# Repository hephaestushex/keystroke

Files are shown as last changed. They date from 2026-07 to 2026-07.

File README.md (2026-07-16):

Keystroke Picture








# Keystroke

_A mini piano-based arcade game, based off the arcade game Grand Piano Keys_

by [@crkalapat](https://github.com/crkalapat), [@hephaestushex](https://github.com/hephaestushex) and [@ceansounet](https://github.com/ceansounet)

_Demo placeholder here_

## How to Play

On bootup, Keystroke will show the title screen, and the current high score. Hit any one of
the four piano keys at the bottom, and gameplay will start immediately along with a 30 second timer.

On screen, there will be colored rectangles that correspond to a key that you must physically
press on the arcade cabinet. Hitting the correct key will cause the next key to fall down for you to
hit. Hitting the wrong key will cause a brief waiting penalty, indicating by the flashing wrong key,
but you can continue playing (if there's time left) after the penalty.

Once 30 seconds ends (as indicated by the 4 digit 7 segment display), the game will be over. You can
view your score, and you will also be notified if you beat the high score, which is stored in flash
memory.

## Features

- 4 Cherry MX Compatible Key Switches
- 2.8" TFT LCD Display (ST7789)
- 30 mm Speaker with PAM8403 amp
- 4 Digit 7 Segment Display (TM1637)
- Orpheus Pico v2 MCU

## Firmware

Keystroke uses PlatformIO, with earlephilhower's build.

## Schematic

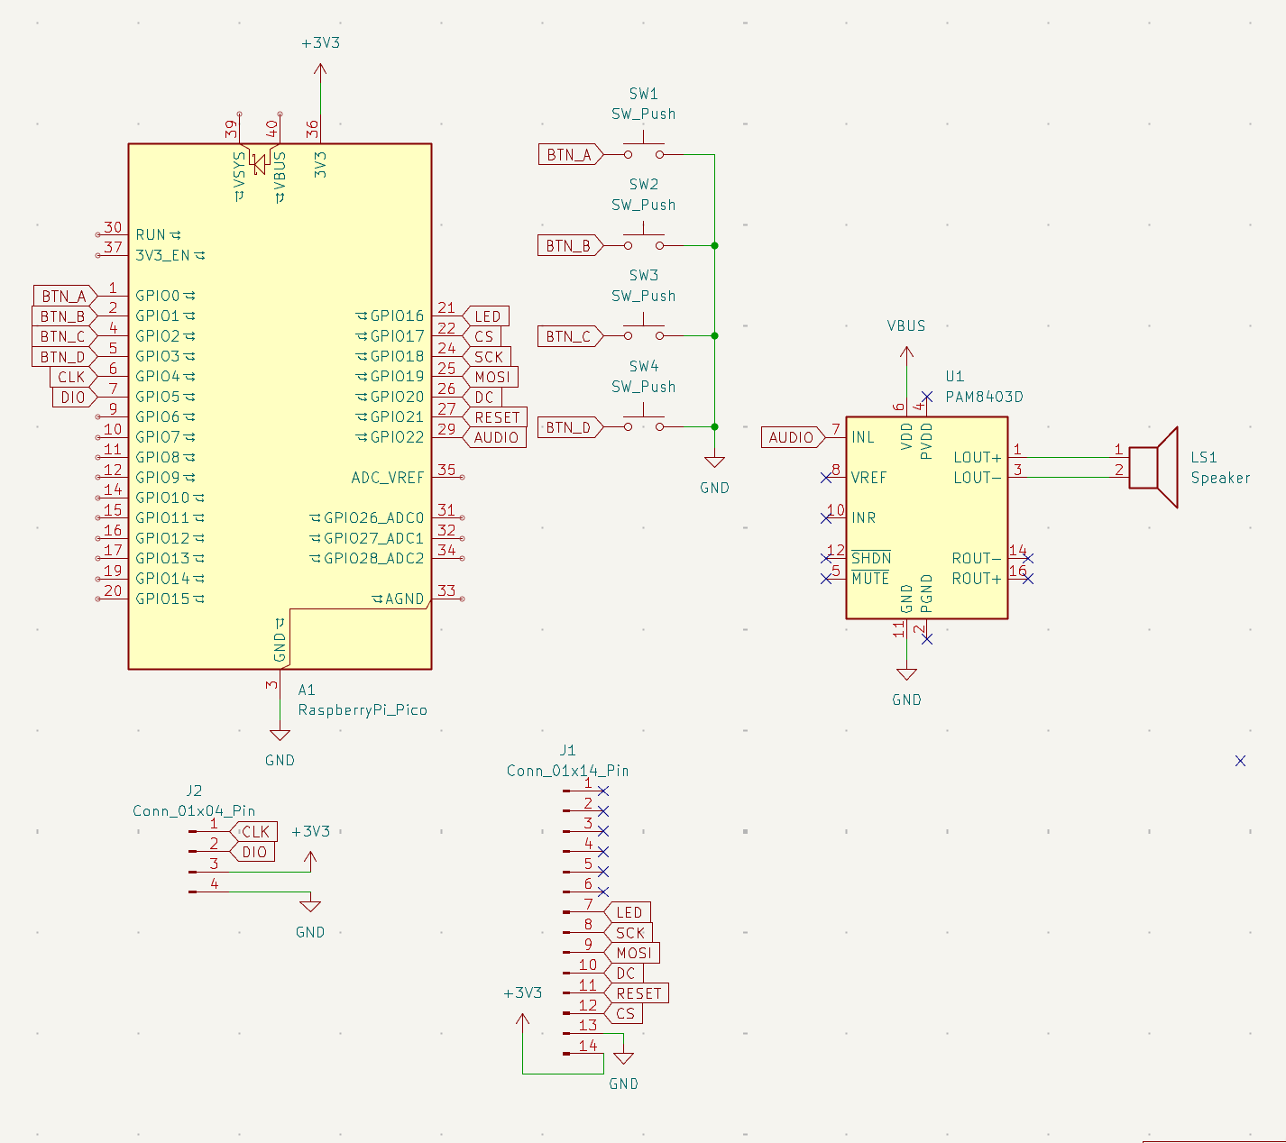
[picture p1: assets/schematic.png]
Schematic Picture


## CAD

You can view the full assembled cabinet as a STEP file under the `cad/` subdirectory, or [view the CAD on OnShape.](https://cad.onshape.com/documents/00226f2798e720e0cd69b425/w/7683bf336800655d27df2c58/e/37cc4361323e3d3f5d8912c6)

## BOM
- 1 2.8" TFT LCD Module (ST7789)
- 1 30mm Speaker (8 ohm)
- 1 Orpheus Pico v2 (any pico compatible rp2040 will work)
- 1 PAM8403 Module
- 1 4 Digit 7 Segment Display (TM6317 with 4 pins needed)

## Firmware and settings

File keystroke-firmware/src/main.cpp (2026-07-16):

#include <Arduino.h>
#include <SPI.h>
#include <PWMAudio.h>
#include <Adafruit_GFX.h>
#include <Adafruit_ST7789.h>
#include <TM1637Display.h>
#include <EEPROM.h>
#include <math.h>
#include "song_types.h"

// Pin Mapping
#define BTN_A     0
#define BTN_B     1
#define BTN_C     2
#define BTN_D     3

#define TM_CLK    4
#define TM_DIO    5

#define TFT_LED   16
#define TFT_CS    17
#define TFT_SCK   18
#define TFT_MOSI  19
#define TFT_DC    20
#define TFT_RST   21

#define AUDIO_PIN 22   // PAM8403 INL

const int BTN_PINS[4] = {BTN_A, BTN_B, BTN_C, BTN_D};

const int      GAME_TIME        = 30;              // round length (s)
const uint32_t PENALTY_MS       = 3000;            // penalty length (ms)
const int      NOTE_DURATION_MS = 250;             // tone length (ms)
const uint16_t KEY_COLOR        = ST77XX_BLUE;     // key color
const uint32_t DEBOUNCE_MS      = 25;              // min quiet time before a press counts

Adafruit_ST7789 tft(&SPI, TFT_CS, TFT_DC, TFT_RST);
TM1637Display   sevenseg(TM_CLK, TM_DIO);
PWMAudio        pwm(AUDIO_PIN);

const uint32_t SAMPLE_RATE = 22050;
const int NUM_VOICES = 6; // headroom for fast presses overlapping still-decaying notes

struct Voice {
  bool active = false;
  float freq = 0;
  uint32_t totalSamples = 0;
  uint32_t sampleIndex = 0;
};
Voice voices[NUM_VOICES];
float masterVolume = 0.25f;

int allocateVoice() {
  for (int i = 0; i < NUM_VOICES; i++) if (!voices[i].active) return i;
  int best = 0;
  uint32_t leastRemaining = UINT32_MAX;
  for (int i = 0; i < NUM_VOICES; i++) {
    uint32_t remaining = voices[i].totalSamples - voices[i].sampleIndex;
    if (remaining < leastRemaining) { leastRemaining = remaining; best = i; }
  }
  return best;
}

void playNote(float freqHz, int durationMs) {
  if (freqHz <= 0) return;
  int v = allocateVoice();
  voices[v].freq = freqHz;
  voices[v].totalSamples = (uint32_t)((durationMs / 1000.0f) * SAMPLE_RATE);
  voices[v].sampleIndex = 0;
  voices[v].active = true;
}

void audioTick() {
  while (pwm.availableForWrite() > 0) {
    float mixed = 0.0f;
    for (int i = 0; i < NUM_VOICES; i++) {
      Voice &vc = voices[i];
      if (!vc.active) continue;
      float t = (float)vc.sampleIndex / SAMPLE_RATE;
      float remaining = (float)(vc.totalSamples - vc.sampleIndex) / SAMPLE_RATE;
      float envelope = 1.0f;
      if (t < 0.005f) envelope = t / 0.005f;
      else if (remaining < 0.005f) envelope = remaining / 0.005f;
      mixed += sinf(2.0f * PI * vc.freq * t) * envelope * (1.0f / NUM_VOICES);

      vc.sampleIndex++;
      if (vc.sampleIndex >= vc.totalSamples) vc.active = false;
    }
    mixed = tanhf(mixed * 1.8f);

    int16_t sample = (int16_t)(mixed * 16000.0f * masterVolume);
    pwm.write(sample, false);
  }
}

const int SCALE[] = {
  NOTE_C4, NOTE_D4, NOTE_E4, NOTE_G4, NOTE_A4,
  NOTE_C5, NOTE_D5, NOTE_E5, NOTE_G5, NOTE_A5,
};
const int SCALE_LEN = sizeof(SCALE) / sizeof(SCALE[0]);

const int QUEUE_LEN = 3; // 0 = cur key, 1 = next key, 2 = last key
struct QueuedKey {
  int freq;
  int lane;
};
QueuedKey noteQueue[QUEUE_LEN];
int scaleIdx = SCALE_LEN / 2;
int lastLane = -1;

QueuedKey generateKey() {
  // Melodic random walk: step at most 2 scale degrees so it sounds like
  // a tune rather than uniform noise.
  scaleIdx = constrain(scaleIdx + (int)random(-2, 3), 0, SCALE_LEN - 1);
  int lane;
  do { lane = random(4); } while (lane == lastLane); // never same key twice in a row
  lastLane = lane;
  return { SCALE[scaleIdx], lane };
}

void refillQueue() {
  lastLane = -1;
  scaleIdx = SCALE_LEN / 2;
  for (int i = 0; i < QUEUE_LEN; i++) noteQueue[i] = generateKey();
}

void advanceQueue() {
  for (int i = 0; i < QUEUE_LEN - 1; i++) noteQueue[i] = noteQueue[i + 1];
  noteQueue[QUEUE_LEN - 1] = generateKey();
}

enum GameState { STATE_IDLE, STATE_PLAYING, STATE_PENALTY, STATE_GAMEOVER };
GameState state = STATE_IDLE;

int score = 0;
int highScore = 0; // persisted to flash
unsigned long gameStartMs = 0;
unsigned long stateEnteredMs = 0;

int penaltyLane = 0;
unsigned long lastBlinkMs = 0;
bool blinkOn = false;

const uint32_t HIGHSCORE_MAGIC = 0x4B455953; // "KEYS"

void loadHighScore() {
  uint32_t magic;
  EEPROM.get(0, magic);
  if (magic == HIGHSCORE_MAGIC) EEPROM.get(sizeof(magic), highScore);
}

void saveHighScore() {
  EEPROM.put(0, HIGHSCORE_MAGIC);
  EEPROM.put(sizeof(HIGHSCORE_MAGIC), highScore);
  EEPROM.commit();
}

// Dirty-check trackers so we only touch the displays on change —
// long SPI bursts stall loop() and starve the audio buffer.
int lastDrawnSecond = -1;
int lastDrawnScore = -1;
int prevQueueLanes[QUEUE_LEN];
bool prevQueueValid = false;

bool lastReading[4] = {true, true, true, true}; // pull-up idle HIGH
unsigned long lastEdgeMs[4] = {0, 0, 0, 0};

int pollButtons() {
  int pressed = -1;
  unsigned long now = millis();
  for (int i = 0; i < 4; i++) {
    bool r = digitalRead(BTN_PINS[i]);
    if (r != lastReading[i]) {
      if (r == LOW && (now - lastEdgeMs[i]) >= DEBOUNCE_MS) pressed = i;
      lastReading[i] = r;
      lastEdgeMs[i] = now;
    }
  }
  return pressed;
}

uint16_t dimColor(uint16_t c) {
  return (c & 0xF7DE) >> 1; // halve each 5-6-5 channel
}

struct KeyRect { int x, y, w, h; };

KeyRect keyRect(int lane, int depth) { // depth 0 = current key, 1-2 = upcoming
  const int ROW_Y[QUEUE_LEN] = {230, 135, 40};
  return { lane * 60 + 5, ROW_Y[depth], 50, 75 };
}

void drawScoreLabel() {
  tft.setCursor(8, 6);
  tft.setTextSize(2);
  tft.setTextColor(ST77XX_WHITE);
  tft.print("SCORE:");
}

void drawScore() {
  if (score == lastDrawnScore) return;
  lastDrawnScore = score;
  tft.fillRect(92, 0, 56, 28, ST77XX_BLACK); // number box only, label is static
  tft.setCursor(94, 6);
  tft.setTextSize(2);
  tft.setTextColor(ST77XX_WHITE);
  tft.print(score);
}

void drawHighScore() { // updated at game over
  char buf[12];
  snprintf(buf, sizeof(buf), "HI:%d", highScore);
  tft.setTextSize(2);
  tft.setTextColor(ST77XX_WHITE);
  tft.setCursor(236 - (int)strlen(buf) * 12, 6);
  tft.print(buf);
}

void drawKeys() {
  // Lazy rects: per row, touch the screen only if that row's block
  // actually moved — erase the old lane, fill the new one, nothing else.
  for (int d = 0; d < QUEUE_LEN; d++) {
    if (prevQueueValid && prevQueueLanes[d] == noteQueue[d].lane) continue;
    if (prevQueueValid) {
      KeyRect r = keyRect(prevQueueLanes[d], d);
      tft.fillRect(r.x, r.y, r.w, r.h, ST77XX_BLACK);
    }
    KeyRect r = keyRect(noteQueue[d].lane, d);
    tft.fillRect(r.x, r.y, r.w, r.h, d == 0 ? KEY_COLOR : dimColor(KEY_COLOR));
    prevQueueLanes[d] = noteQueue[d].lane;
  }
  prevQueueValid = true;
}

void drawTimer() {
  long remaining = (long)GAME_TIME - (long)((millis() - gameStartMs) / 1000);
  if (remaining < 0) remaining = 0;
  if ((int)remaining == lastDrawnSecond) return; // only update once per second
  lastDrawnSecond = remaining;

  int mins = remaining / 60;
  int secs = remaining % 60;
  sevenseg.showNumberDecEx(mins * 100 + secs, 0b01000000, true); // 0x40 = colon bit
}

bool timeUp() {
  return (millis() - gameStartMs) >= (unsigned long)GAME_TIME * 1000UL;
}

void enterIdle() {
  state = STATE_IDLE;
  stateEnteredMs = millis();
  tft.fillScreen(ST77XX_BLACK);
  tft.setTextSize(4);
  tft.setTextColor(KEY_COLOR);
  tft.setCursor(12, 110);
  tft.print("KEYSTROKE");
  tft.setTextSize(2);
  tft.setTextColor(ST77XX_WHITE);
  tft.setCursor(42, 180);
  tft.print("PRESS ANY KEY");
  sevenseg.showNumberDecEx(GAME_TIME, 0b01000000, true); // shows 00:30
}

void startRound() {
  randomSeed(micros()); // seeded by human keypress timing
  state = STATE_PLAYING;
  score = 0;
  lastDrawnScore = -1;
  lastDrawnSecond = -1;
  prevQueueValid = false;
  refillQueue();
  tft.fillScreen(ST77XX_BLACK);
  drawScoreLabel();
  drawScore();
  drawHighScore();
  drawKeys();
  gameStartMs = millis();
  drawTimer();
}

void enterPenalty(int lane) {
  state = STATE_PENALTY;
  stateEnteredMs = millis();
  penaltyLane = lane;
  blinkOn = true;
  lastBlinkMs = millis();

  // keep correct key on screen
  KeyRect r = keyRect(lane, 0);
  tft.fillRect(r.x, r.y, r.w, r.h, ST77XX_RED);
}

void updatePenalty() {
  unsigned long now = millis();
  if (now - lastBlinkMs >= 300) { // flash the wrong key red
    lastBlinkMs = now;
    blinkOn = !blinkOn;
    KeyRect r = keyRect(penaltyLane, 0);
    tft.fillRect(r.x, r.y, r.w, r.h, blinkOn ? ST77XX_RED : ST77XX_BLACK);
  }
  if (now - stateEnteredMs >= PENALTY_MS) {
    state = STATE_PLAYING;
    KeyRect r = keyRect(penaltyLane, 0); // erase the red block, field is intact
    tft.fillRect(r.x, r.y, r.w, r.h, ST77XX_BLACK);
  }
}

void enterGameOver() {
  state = STATE_GAMEOVER;
  stateEnteredMs = millis();
  bool newHigh = score > highScore;
  if (newHigh) {
    highScore = score;
    saveHighScore();
  }
  sevenseg.showNumberDec(score);

  tft.fillScreen(ST77XX_BLACK);
  tft.setTextSize(3);
  tft.setTextColor(ST77XX_WHITE);
  tft.setCursor(30, 60);
  tft.print("TIME'S UP!");

  tft.setTextSize(6);
  tft.setTextColor(KEY_COLOR);
  int digits = score >= 100 ? 3 : (score >= 10 ? 2 : 1);
  tft.setCursor((240 - digits * 36) / 2, 130);
  tft.print(score);

  tft.setTextSize(2);
  tft.setTextColor(ST77XX_WHITE);
  tft.setCursor(96, 195);
  tft.print("KEYS");
  if (newHigh) {
    tft.setTextColor(ST77XX_YELLOW);
    tft.setCursor(66, 230);
    tft.print("NEW HIGH!");
  }
  tft.setTextColor(ST77XX_WHITE);
  tft.setCursor(42, 270);
  tft.print("PRESS ANY KEY");
}

void handlePress(int lane) {
  if (lane == noteQueue[0].lane) {
    playNote(noteQueue[0].freq, NOTE_DURATION_MS);
    score++;
    advanceQueue();
    drawKeys();
    drawScore();
  } else {
    enterPenalty(lane);
  }
}

void setup() {
  Serial.begin(115200);

  // Screen
  SPI.begin();
  tft.init(240, 320);
  tft.setSPISpeed(62500000);
  tft.setRotation(0);
  tft.invertDisplay(false); // flip to false if your panel shows inverted colors
  pinMode(TFT_LED, OUTPUT);
  digitalWrite(TFT_LED, HIGH);
  tft.fillScreen(ST77XX_BLACK);

  // 7 Segment 4 Digit Display
  sevenseg.setBrightness(7);
  sevenseg.clear();

  // Keys
  for (int i = 0; i < 4; i++) pinMode(BTN_PINS[i], INPUT_PULLUP);

  // Speaker
  pwm.setBuffers(8, 64);
  pwm.begin(SAMPLE_RATE);

  // High score from flash
  EEPROM.begin(256);
  loadHighScore();

  enterIdle();
}

void loop() {
  audioTick(); // runs every iteration to keep audio glitch-free

  int pressed = pollButtons();

  switch (state) {
    case STATE_IDLE:
      if (pressed >= 0) startRound();
      break;

    case STATE_PLAYING:
      if (timeUp()) { enterGameOver(); break; }
      drawTimer();
      if (pressed >= 0) handlePress(pressed);
      break;

    case STATE_PENALTY:
      if (timeUp()) { enterGameOver(); break; } // penalty eats into the clock
      drawTimer();
      updatePenalty(); // presses ignored until the flash ends
      break;

    case STATE_GAMEOVER:
      // small lockout so a press from the final moments doesn't insta-restart
      if (pressed >= 0 && millis() - stateEnteredMs > 800) startRound();
      break;
  }
}

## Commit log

2026-07-15 initial schematic
    [keystroke.kicad_sch]
2026-07-15 finished schematic
    [keystroke.kicad_sch]
2026-07-16 mvp code
    [keystroke.kicad_sch]
2026-07-16 Add first version of main assembly CAD file
2026-07-16 Make timer count down, test UI change
2026-07-16 Fix minor syntax errors
    [main.cpp]
2026-07-16 Add BOM to README
2026-07-16 Update README with images and BOM details
    Added additional images to the README and updated BOM items with specific details.
